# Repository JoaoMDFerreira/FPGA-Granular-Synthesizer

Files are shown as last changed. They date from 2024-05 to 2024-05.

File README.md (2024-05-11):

# FPGA Implementation of a Real-time Synthetic-Based Granular Synthesizer
This repo contains the source code backup of the thesis. The topic of the thesis is "FPGA Implementation of a Real-time Synthetic-Based Granular Synthesizer".
A diagram of the implementation is shown below.
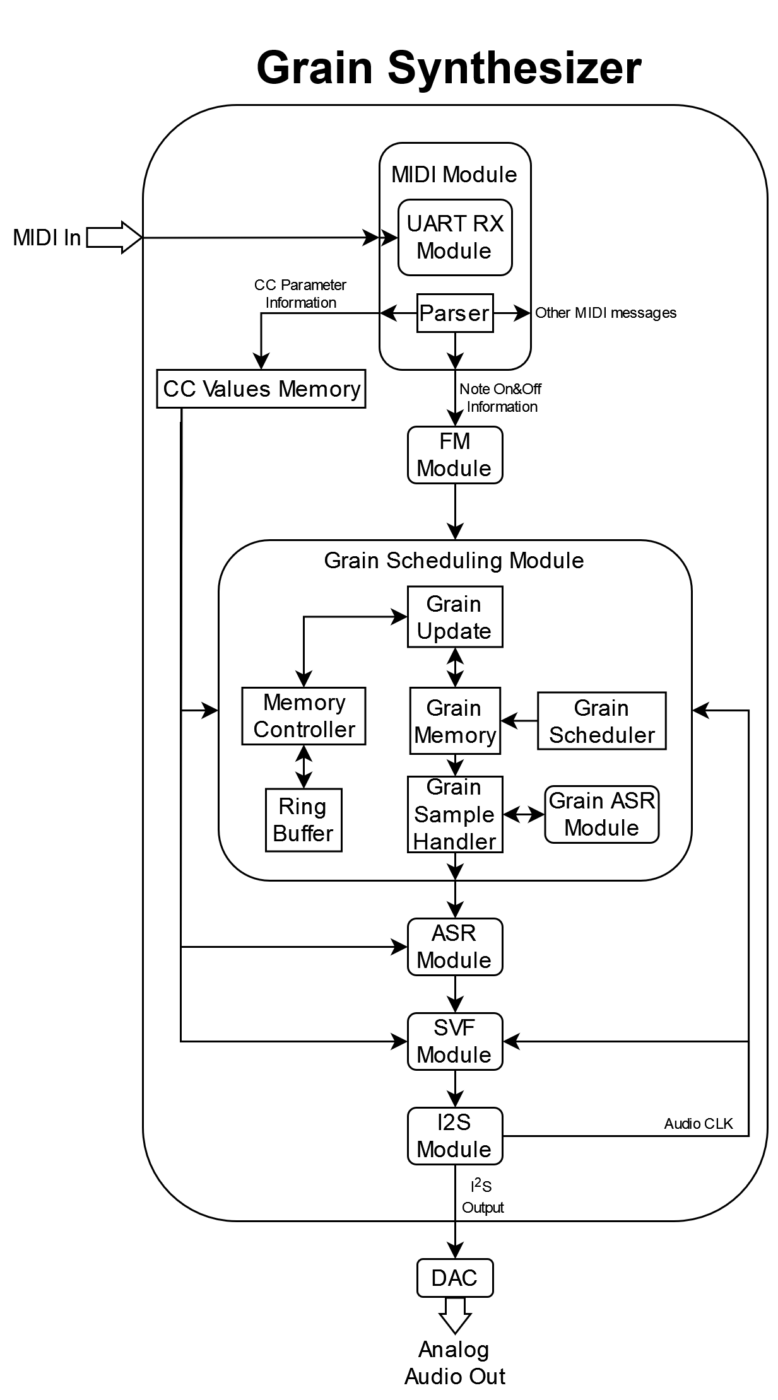
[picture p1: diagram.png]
Implementation Diagram


The final binary is given as BOOT.bin.

## VHDL Source Files
The VHDL project was not backed up, only its source files. These files are available in the vhdl_src folder.

## PCB Files
The KiCad files for a breakout board developed for the Z-turn board V2 are given in the Breakout folder.

## MATLAB Source Files
MATLAB source files are given in the matlab_src.

## Extras
Some extra files are contained in the misc_src folder. Some of these are scripts used to generate plots for the thesis, there are some exploratory scripts towards pitch_shifting that was future work for the thesis and finally there is a C script used to generate code for the MIDI_LUT.

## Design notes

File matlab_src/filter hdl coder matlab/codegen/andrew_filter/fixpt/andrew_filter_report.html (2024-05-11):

### Generated on 2023-07-12 17:33:15

The following table shows fixed point instrumentation results

## Fixed-Point Report andrew_filter

Simulation Coverage | Code
100% | function [y] = andrew_filter(in,MIDI_CC_FREQ,CC_RES,type) persistent low; %https://www.mathworks.com/help/hdlcoder/ug/optimize-feedback-loop-design-and-maintain-high-data-precision-for-hdl-code-generation.html persistent band;
Once | if isempty(low); low = 0; end if isempty(band); band = 0; end
100% | loaded = coder.load('MIDI_CC_to_internal_freq.mat'); filter_internal_freq = loaded.filter_internal_freq; %%check LUT_from_MIDI_Note.m damp_freq = loaded.damp_freq; freq = filter_internal_freq(MIDI_CC_FREQ+1); res = CC_RES/127.0; damp=min(2.0*(1.0 -res*2^-2), damp_freq(MIDI_CC_FREQ+1)); notch = in - damp*band; low = low + freq*band; high = notch - low; band = freq*high + band; switch type
25% | case 1 out = 0.5*high; case 3 out = 0.5*notch; case 2 out = 0.5*band; otherwise out = 0.5*low;
100% | end notch = in - damp*band; low = low + freq*band; high = notch - low; band = freq*high + band; switch type
25% | case 1 y = out + 0.5*high; case 3 y = out + 0.5*notch; case 2 y = out + 0.5*band; otherwise y = out + 0.5*low;
100% | end y = floor(y); end

Variable Name | Type | Sim Min | Sim Max | Static Min | Static Max | Whole Number | ProposedType (Best For WL = 16)
CC_RES | double | 0 | 127 | | | Yes | numerictype(0, 7, 0)
MIDI_CC_FREQ | double | 0 | 127 | | | Yes | numerictype(0, 7, 0)
band | double | -32311.663196332738 | 34925.41665146108 | | | No | numerictype(1, 16, -1)
damp | double | 1.2326752784371549 | 2 | | | No | numerictype(0, 16, 14)
damp_freq | double 1 x 128 | 1.2326752784371549 | 2 | | | No | numerictype(0, 16, 14)
filter_internal_freq | double 1 x 128 | 0.0005351047813369359 | 1.1166838558950394 | | | No | numerictype(0, 16, 15)
freq | double | 0.0005351047813369359 | 1.1166838558950394 | | | No | numerictype(0, 16, 15)
high | double | -60151.40516233119 | 56730.470785388075 | | | No | numerictype(1, 16, -1)
in | double | -32757.127079136506 | 32765.90295982157 | | | No | numerictype(1, 16, 0)
loaded | struct
loaded.damp_freq | double 1 x 128 | 1.2326752784371549 | 2 | | | No | numerictype(0, 16, 14)
loaded.filter_internal_freq | double 1 x 128 | 0.0005351047813369359 | 1.1166838558950394 | | | No | numerictype(0, 16, 15)
low | double | -42841.7216706145 | 49985.56701657598 | | | No | numerictype(1, 16, -1)
notch | double | -55979.872226648375 | 68487.43844321661 | | | No | numerictype(1, 16, -2)
out | double | -27989.936113324187 | 34243.719221608306 | | | No | numerictype(1, 16, -1)
res | double | 0 | 1 | | | No | numerictype(0, 16, 15)
type | double | 0 | 3 | | | Yes | numerictype(0, 2, 0)
y | double | -48295 | 38426.585370044944 | | | No | numerictype(1, 16, -1)

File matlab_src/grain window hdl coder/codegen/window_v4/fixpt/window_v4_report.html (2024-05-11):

### Generated on 2024-03-03 22:46:27

The following table shows fixed point instrumentation results

## Fixed-Point Report window_v4

Simulation Coverage | Code
100% | function out = window_v4(CC_attack, CC_release,current,size,in) persistent interrim_1;
Once | if isempty(interrim_1) interrim_1 = 1; end
100% | persistent interrim_2;
Once | if isempty(interrim_2) interrim_2 = 1; end
100% | attack = floor((CC_attack+1)/255 *size)+1; release = floor((CC_release+1)/255 *size)+1;
24% | if current <= attack interrim_1 = (current-1) *in; out = interrim_1/attack;
52% | elseif current < size - release out = in;
24% | else %out = (size - current) /release *in; interrim_2 = (size-current) *in; out = interrim_2/release; end
100% | end

Variable Name | Type | Sim Min | Sim Max | Static Min | Static Max | Whole Number | ProposedType (Best For WL = 16)
CC_attack | double | 0 | 120 | | | Yes | numerictype(0, 7, 0)
CC_release | double | 0 | 120 | | | Yes | numerictype(0, 7, 0)
attack | double | 1 | 2278 | | | Yes | numerictype(0, 12, 0)
current* | double | 1 | 4800 | | | Yes | numerictype(0, 13, 0)
in | double | -32766.998244725935 | 32766.999999688083 | | | No | numerictype(1, 16, 0)
interrim_1* | double | -74569691.77370726 | 66876492.439555064 | | | No | numerictype(1, 28, 0)
interrim_2* | double | -66876492.43955507 | 74628348.0223639 | | | No | numerictype(1, 28, 0)
out | double | -32766.998244725935 | 32766.998244725935 | | | No | numerictype(1, 16, 0)
release | double | 1 | 2278 | | | Yes | numerictype(0, 12, 0)
size* | double | 1 | 4800 | | | Yes | numerictype(0, 13, 0)

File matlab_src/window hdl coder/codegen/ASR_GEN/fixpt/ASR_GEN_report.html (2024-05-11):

### Generated on 2024-02-12 22:14:36

The following table shows fixed point instrumentation results

## Fixed-Point Report ASR_GEN

Simulation Coverage | Code
100% | function ASR_OUT = ASR_GEN(ATTACK_CC, RELEASE_CC,MAX_ATTACK_MS,MAX_RELEASE_MS,CLK_FREQ,NOTE_ON,ASR_IN) % 0 => Idle; 1 => Attack; 2 => Sustain; 3 => Release persistent state;
Once | if isempty(state) state = 0; end
100% | persistent attack_ptr;
Once | if isempty(attack_ptr) attack_ptr = 0; end
100% | persistent release_ptr;
Once | if isempty(release_ptr) release_ptr = 0; end
100% | attack_clks = floor(CLK_FREQ*MAX_ATTACK_MS/1000 *ATTACK_CC/128); release_clks = floor(CLK_FREQ*MAX_RELEASE_MS/1000 *RELEASE_CC/128); switch state
32% | case 0 %Idle state ASR_OUT = 0;

100%

if NOTE_ON == 1
attack_ptr = 0;
state = 1;
end

case 1 %Attack state
if NOTE_ON == 1
if attack_ptr >= attack_clks
state = 2;
end
else
state = 3;
release_ptr = attack_ptr;
end
if attack_clks == 0
ASR_OUT = 0;
else
ASR_OUT = floor(attack_ptr/attack_clks *ASR_IN);
end
attack_ptr = attack_ptr + 1;

case 2 %Sustain state
ASR_OUT = ASR_IN;
if NOTE_ON == 0
state = 3;
release_ptr = release_clks;
end

case 3 %Release state
if NOTE_ON == 1 || release_ptr == 0
state = 0;
else
release_ptr = release_ptr - 1;
end
if release_clks == 0
ASR_OUT = 0;
else
ASR_OUT = floor(release_ptr/release_clks *ASR_IN);
end

otherwise
ASR_OUT = 0;
state = 0;
end
end

Variable Name | Type | Sim Min | Sim Max | Static Min | Static Max | Whole Number | ProposedType (Best For WL = 16)
ASR_IN | double | -32766.999561272904 | 32766.99956127291 | | | No | numerictype(1, 16, 0)
ASR_OUT | double | -32766.999561272904 | 32766.989031823246 | | | No | numerictype(1, 16, 0)
ATTACK_CC | double | 0 | 120 | | | Yes | numerictype(0, 7, 0)
CLK_FREQ* | double | 48000 | 48000 | | | Yes | numerictype(0, 27, 0)
MAX_ATTACK_MS* | double | 100 | 100 | | | Yes | numerictype(0, 10, 0)
MAX_RELEASE_MS* | double | 100 | 100 | | | Yes | numerictype(0, 10, 0)
NOTE_ON | double | 0 | 1 | | | Yes | numerictype(0, 1, 0)
RELEASE_CC | double | 0 | 120 | | | Yes | numerictype(0, 7, 0)
attack_clks* | double | 0 | 4500 | | | Yes | numerictype(0, 27, 0)
attack_ptr* | double | 0 | 4319 | | | Yes | numerictype(0, 27, 0)
release_clks* | double | 0 | 4500 | | | Yes | numerictype(0, 27, 0)
release_ptr* | double | 0 | 4318 | | | Yes | numerictype(0, 27, 0)
state | double | 0 | 3 | | | Yes | numerictype(0, 2, 0)

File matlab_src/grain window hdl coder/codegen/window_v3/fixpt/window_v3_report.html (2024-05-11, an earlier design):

### Generated on 2024-02-04 21:20:42

The following table shows fixed point instrumentation results

## Fixed-Point Report window_v3

Simulation Coverage | Code
100% | function out = window_v3(CC_attack, CC_release,current,size,in) attack = floor((CC_attack+1)/255 *size)+1; release = floor((CC_release+1)/255 *size)+1; sustain = size - attack - release;
24% | if current <= attack out = (current-1)/attack *in;
52% | elseif current < attack + sustain out = in;
24% | else out = (1 - (current - attack - sustain)/release) *in; end
100% | end

Variable Name | Type | Sim Min | Sim Max | Static Min | Static Max | Whole Number | ProposedType (Best For WL = 16)
CC_attack | double | 0 | 120 | | | Yes | numerictype(0, 7, 0)
CC_release | double | 0 | 120 | | | Yes | numerictype(0, 7, 0)
attack | double | 1 | 22303 | | | Yes | numerictype(0, 15, 0)
current | double | 1 | 47001 | | | Yes | numerictype(0, 16, 0)
in | double | -32766.999999998614 | 32766.999999998156 | | | No | numerictype(1, 16, 0)
out | double | -32766.999952809816 | 32766.999955083706 | | | No | numerictype(1, 16, 0)
release | double | 1 | 22303 | | | Yes | numerictype(0, 15, 0)
size | double | 1 | 47001 | | | Yes | numerictype(0, 16, 0)
sustain | double | -1 | 46631 | | | Yes | numerictype(1, 17, 0)

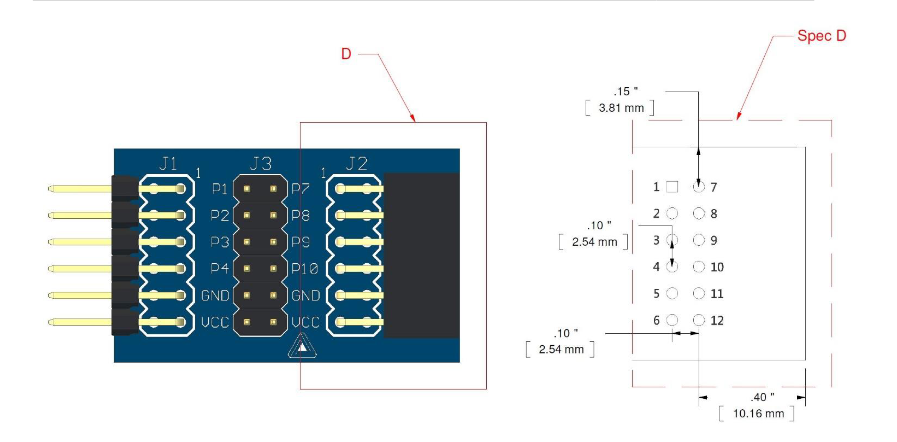
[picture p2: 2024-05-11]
Breakout/Breakout/PMOD.png

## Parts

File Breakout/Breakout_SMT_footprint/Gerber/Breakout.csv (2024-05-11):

Comment | Designator | Footprint | LCSC Part Number
1N4148 | D1 | Device:D | C402212
3mm LED | D2, D3, D4, D5, D6, D7, D8, D9 | Device:LED | C7433021
2x06 Right Angle Pin Header 2.54mm | J1, J3 | Z_Turn_Board_Lib:PMOD_Conn | C5383091
DIN-5_180Degree_Female | J2 | Connector:DIN-5_180degree | C2939346
1x06 Right Angle Pin Header 2.54mm | J4 | Connector:Conn_01x06_Pin | C19190480
1x32 Straight Pin Header 2.54mm | J5 | Connector:Conn_01x31_Pin | C7430388
1x04 Right Angle Pin Header 2.54mm | J6 | Connector:Conn_01x04_Pin | C2935929
02x40 Straight Pin Header 1.27mm | J7, J8 | Connector_Generic:Conn_02x40_Odd_Even | C545212
220R | R1 | Device:R_Small | C1367947
510R | R2 | Device:R_Small | C1396546
H11L1 | U1 | Isolator:H11L1 | C78588

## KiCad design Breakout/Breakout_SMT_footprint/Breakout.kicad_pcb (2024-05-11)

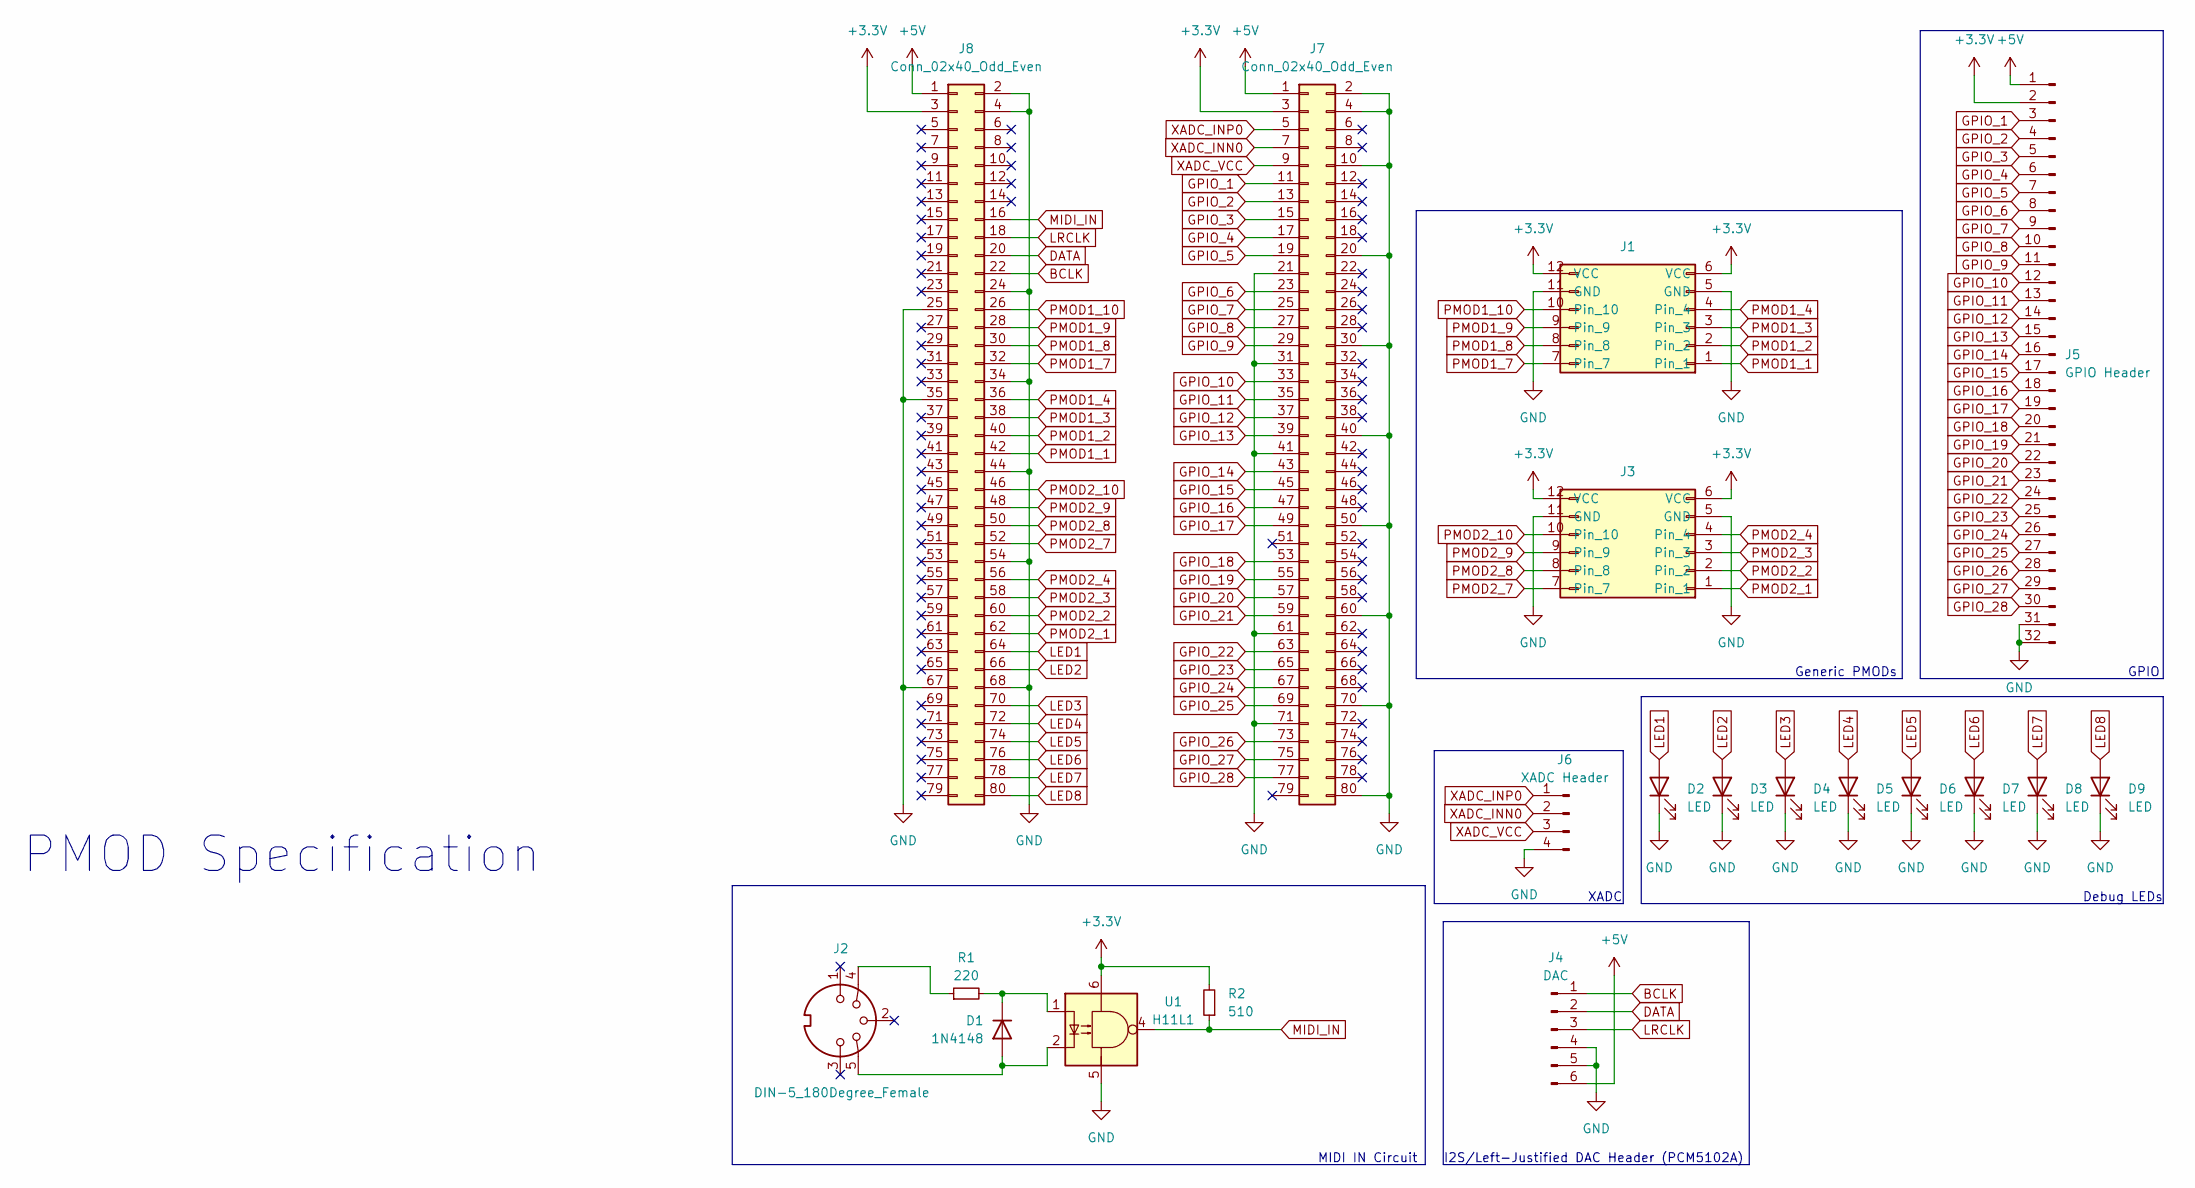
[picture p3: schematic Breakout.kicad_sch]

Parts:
D1: 1N4148; D_DO-35_SOD27_P7.62mm_Horizontal; LCSC C402212
D2, D3, D4, D5, D6, D7, D8, D9: LED; LED_D3.0mm; LCSC C7433021
J1, J3: PMOD; LCSC C5383091
J2: DIN-5_180Degree_Female; MIDI_DIN5; LCSC C2939346
J4: DAC; PinHeader_1x06_P2.54mm_Horizontal; LCSC C19190480
J5: GPIO Header; PinHeader_1x32_P2.54mm_Vertical; LCSC C7430388
J6: XADC Header; PinSocket_1x04_P2.54mm_Vertical; LCSC C2935929
J7, J8: Conn_02x40_Odd_Even; 2x40 Inverted; LCSC C545212
R1: 220; R_Axial_DIN0204_L3.6mm_D1.6mm_P5.08mm_Horizontal; LCSC C1367947
R2: 510; R_Axial_DIN0204_L3.6mm_D1.6mm_P5.08mm_Horizontal; LCSC C1396546
U1: H11L1; DIP-6_W7.62mm_Socket_LongPads; LCSC C78588

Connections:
+3.3V: J1.6 (VCC), J1.12 (VCC), J3.6 (VCC), J3.12 (VCC), J5.2, J7.3, J8.3, R2.2, U1.6
+5V: J4.6, J5.1, J7.1, J8.1
BCLK: J4.1, J8.22
DATA: J4.2, J8.20
GND: D2.1 (K), D3.1 (K), D4.1 (K), D5.1 (K), D6.1 (K), D7.1 (K), D8.1 (K), D9.1 (K), J1.5 (GND), J1.11 (GND), J3.5 (GND), J3.11 (GND), J4.4, J4.5, J5.31, J5.32, J6.4, J7.2, J7.4, J7.10, J7.20, J7.21, J7.30, J7.31, J7.40, J7.41, J7.50, J7.60, J7.61, J7.70, J7.71, J7.80, J8.2, J8.4, J8.24, J8.25, J8.34, J8.35, J8.44, J8.54, J8.67, J8.68, U1.5
GPIO_1: J5.3, J7.11
GPIO_2: J5.4, J7.13
GPIO_3: J5.5, J7.15
GPIO_4: J5.6, J7.17
GPIO_5: J5.7, J7.19
GPIO_6: J5.8, J7.23
GPIO_7: J5.9, J7.25
GPIO_8: J5.10, J7.27
GPIO_9: J5.11, J7.29
GPIO_10: J5.12, J7.33
GPIO_11: J5.13, J7.35
GPIO_12: J5.14, J7.37
GPIO_13: J5.15, J7.39
GPIO_14: J5.16, J7.43
GPIO_15: J5.17, J7.45
GPIO_16: J5.18, J7.47
GPIO_17: J5.19, J7.49
GPIO_18: J5.20, J7.53
GPIO_19: J5.21, J7.55
GPIO_20: J5.22, J7.57
GPIO_21: J5.23, J7.59
GPIO_22: J5.24, J7.63
GPIO_23: J5.25, J7.65
GPIO_24: J5.26, J7.67
GPIO_25: J5.27, J7.69
GPIO_26: J5.28, J7.73
GPIO_27: J5.29, J7.75
GPIO_28: J5.30, J7.77
LED1: D2.2 (A), J8.64
LED2: D3.2 (A), J8.66
LED3: D4.2 (A), J8.70
LED4: D5.2 (A), J8.72
LED5: D6.2 (A), J8.74
LED6: D7.2 (A), J8.76
LED7: D8.2 (A), J8.78
LED8: D9.2 (A), J8.80
LRCLK: J4.3, J8.18
MIDI_IN: J8.16, R2.1, U1.4
unnamed: D1.2 (A), J2.5, U1.2
unnamed: D1.1 (K), R1.2, U1.1
unnamed: J2.4, R1.1
PMOD1_1: J1.1, J8.42
PMOD1_2: J1.2, J8.40
PMOD1_3: J1.3, J8.38
PMOD1_4: J1.4, J8.36
PMOD1_7: J1.7, J8.32
PMOD1_8: J1.8, J8.30
PMOD1_9: J1.9, J8.28
PMOD1_10: J1.10, J8.26
PMOD2_1: J3.1, J8.62
PMOD2_2: J3.2, J8.60
PMOD2_3: J3.3, J8.58
PMOD2_4: J3.4, J8.56
PMOD2_7: J3.7, J8.52
PMOD2_8: J3.8, J8.50
PMOD2_9: J3.9, J8.48
PMOD2_10: J3.10, J8.46
XADC_INN0: J6.2, J7.7
XADC_INP0: J6.1, J7.5
XADC_VCC: J6.3, J7.9

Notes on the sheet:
PMOD Specification
I2S/Left-Justified DAC Header (PCM5102A)
GPIO
Generic PMODs
Debug LEDs
MIDI IN Circuit
XADC

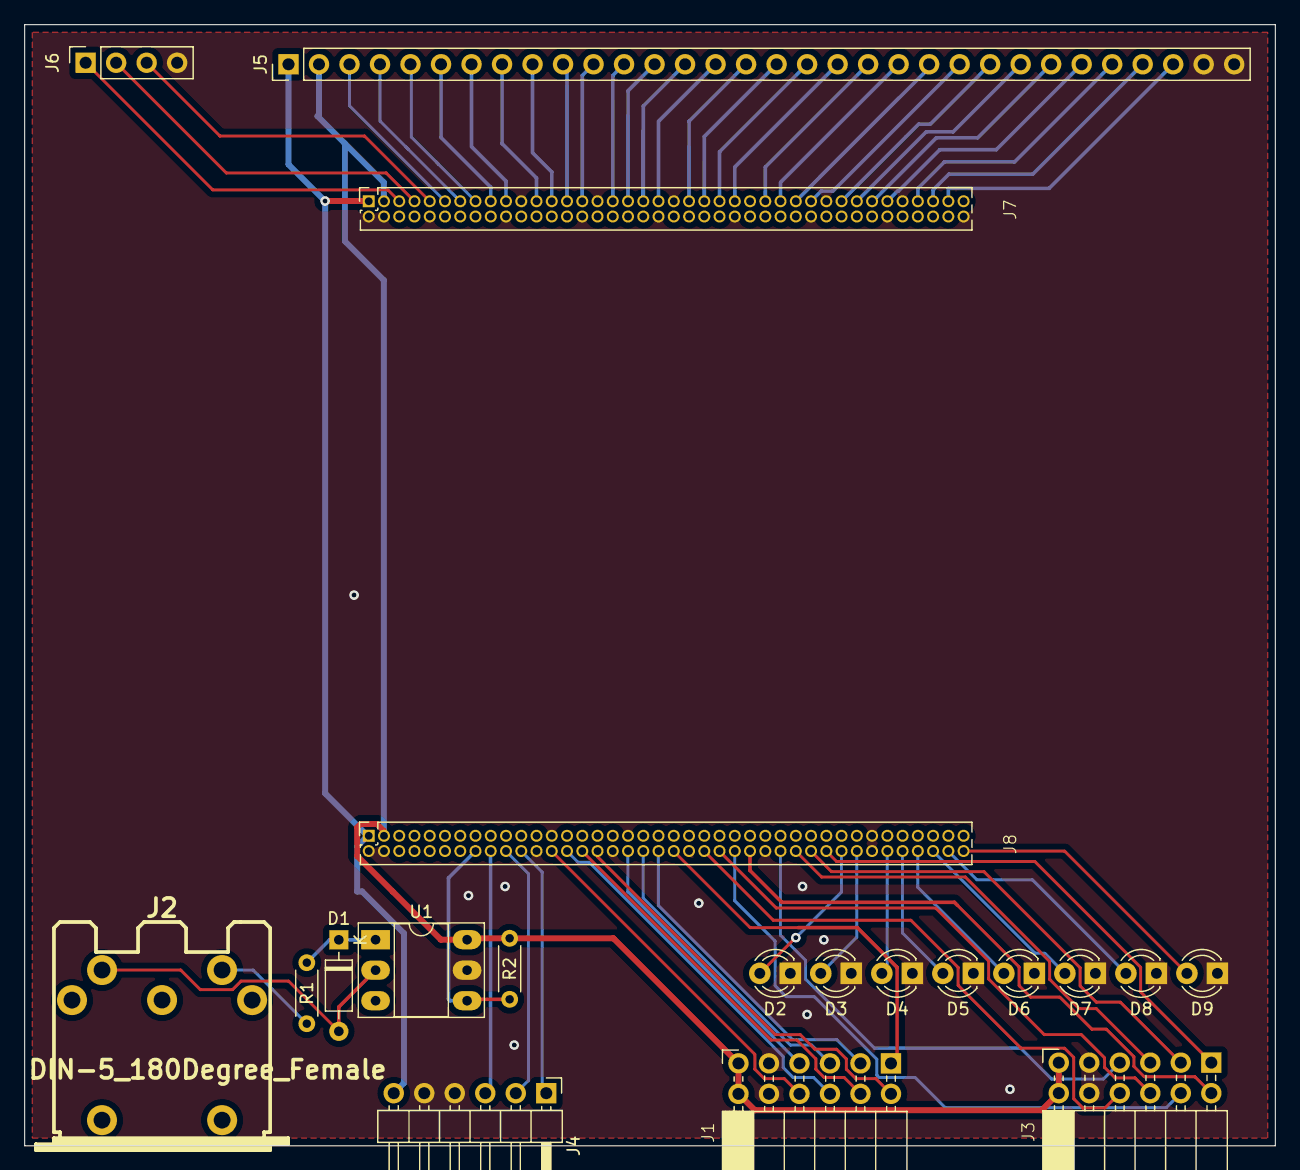
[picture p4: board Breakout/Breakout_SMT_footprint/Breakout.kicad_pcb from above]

Board: 2 copper layers, 104.1 x 93.3 mm, 20 parts (0 on the bottom side), 65 nets.

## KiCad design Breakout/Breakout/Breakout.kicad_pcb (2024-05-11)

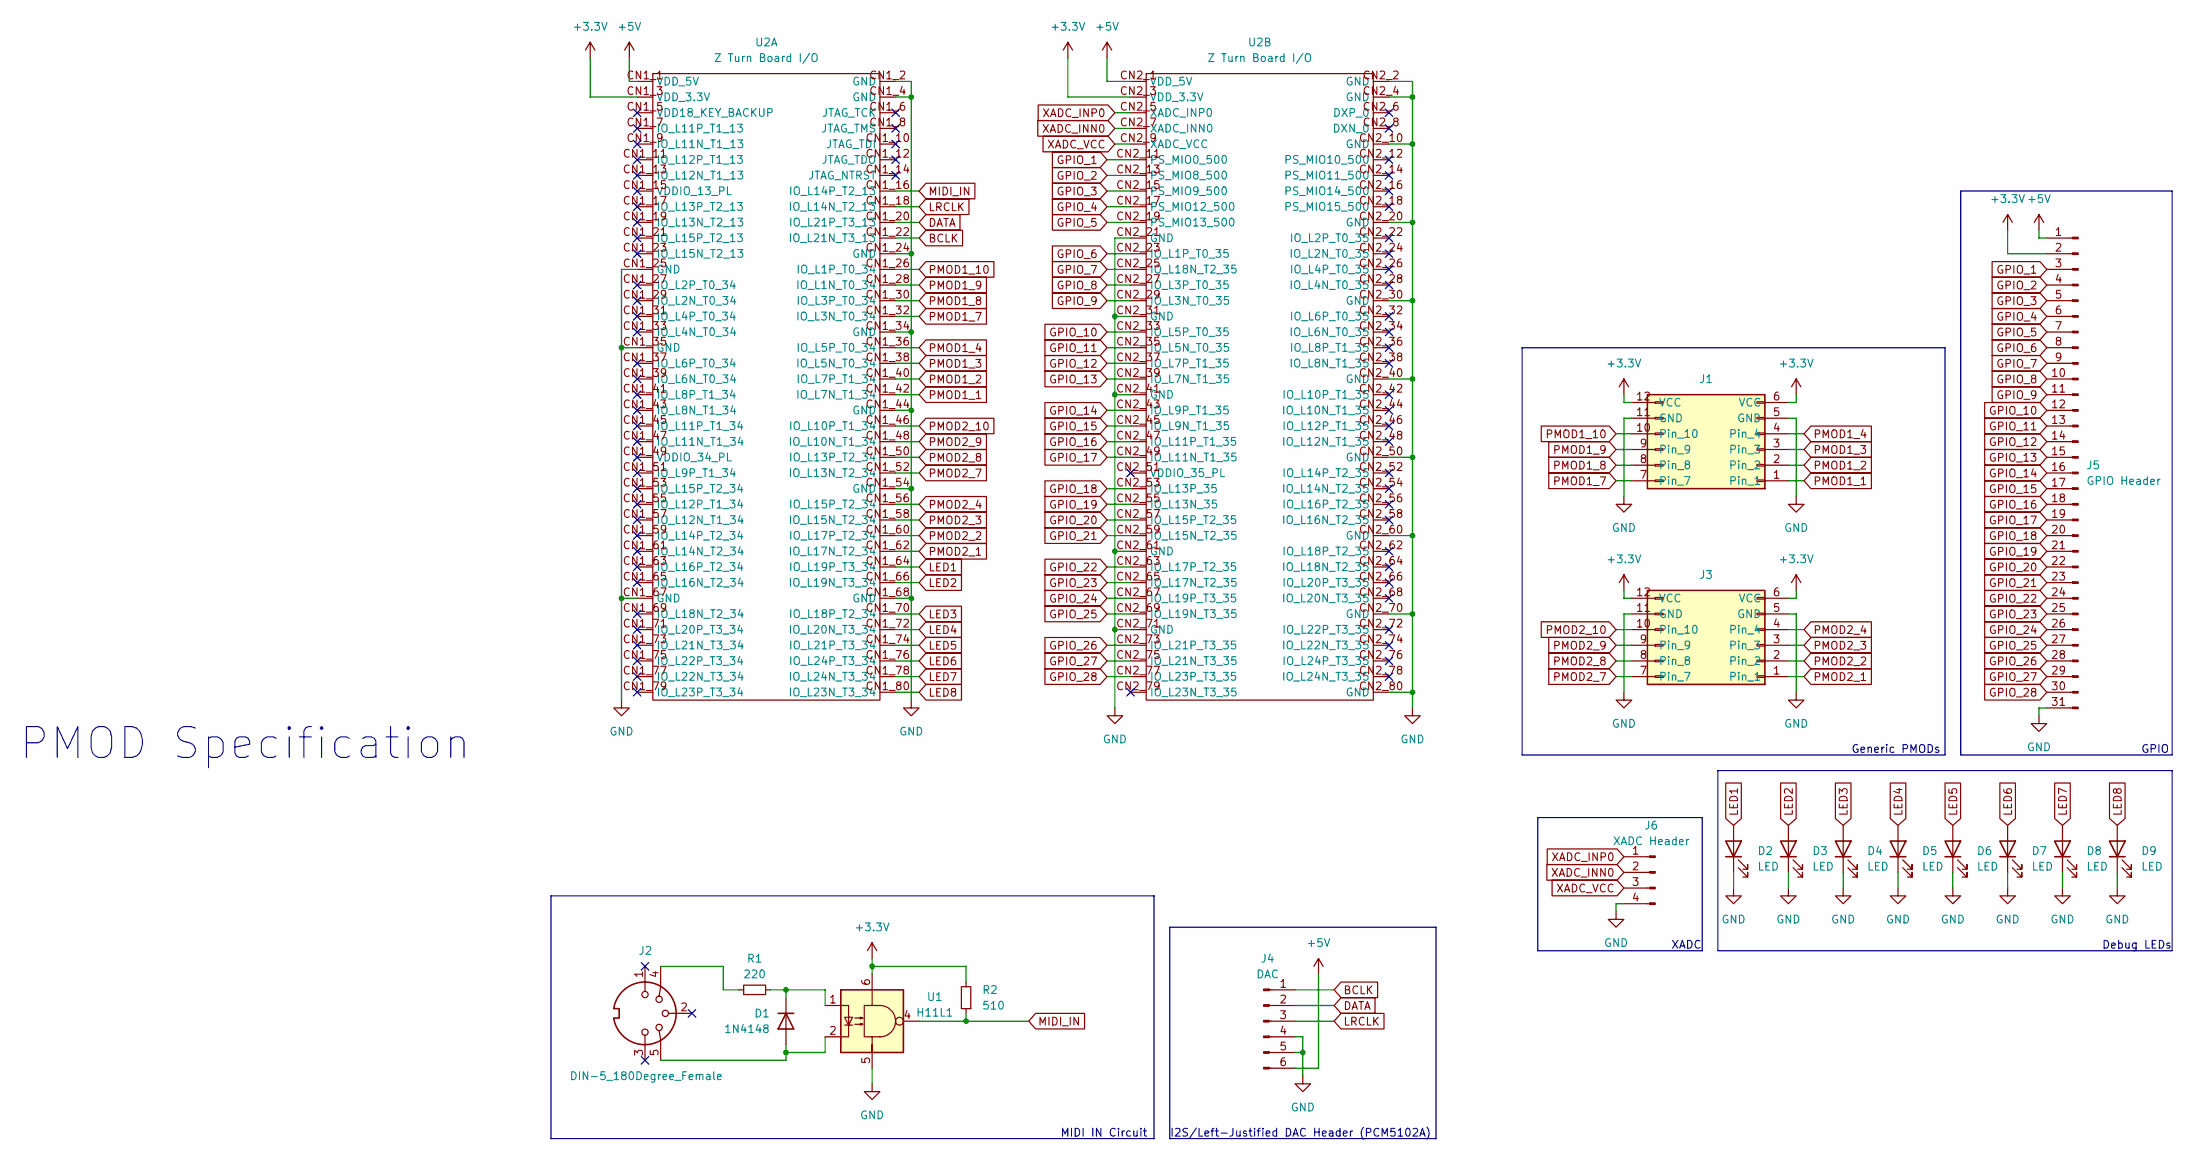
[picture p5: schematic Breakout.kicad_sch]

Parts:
D1: 1N4148; D_DO-35_SOD27_P7.62mm_Horizontal; LCSC C402212
D2, D3, D4, D5, D6, D7, D8, D9: LED; LED_D3.0mm; LCSC C7433021
J1, J3: PMOD; LCSC C5383091
J2: DIN-5_180Degree_Female; MIDI_DIN5; LCSC C2939346
J4: DAC; PinHeader_1x06_P2.54mm_Horizontal; LCSC C19190480
J5: GPIO Header; PinSocket_1x31_P2.54mm_Vertical; LCSC C2883719
J6: XADC Header; PinSocket_1x04_P2.54mm_Vertical; LCSC C18164982
R1: 220; R_Axial_DIN0204_L3.6mm_D1.6mm_P5.08mm_Horizontal; LCSC C1367947
R2: 510; R_Axial_DIN0204_L3.6mm_D1.6mm_P5.08mm_Horizontal; LCSC C1396546
U1: H11L1; DIP-6_W7.62mm_Socket_LongPads; LCSC C78588
U2: Z Turn Board I/O; Z Turn Board IO; LCSC C545212

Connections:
+3.3V: J1.6 (VCC), J1.12 (VCC), J3.6 (VCC), J3.12 (VCC), J5.2, R2.2, U1.6, U2.CN1_3 (VDD_3.3V), U2.CN2_3 (VDD_3.3V)
+5V: J4.6, J5.1, U2.CN1_1 (VDD_5V), U2.CN2_1 (VDD_5V)
BCLK: J4.1, U2.CN1_22 (IO_L21N_T3_13)
DATA: J4.2, U2.CN1_20 (IO_L21P_T3_13)
GND: D2.1 (K), D3.1 (K), D4.1 (K), D5.1 (K), D6.1 (K), D7.1 (K), D8.1 (K), D9.1 (K), J1.5 (GND), J1.11 (GND), J3.5 (GND), J3.11 (GND), J4.4, J4.5, J5.31, J6.4, U1.5, U2.CN1_2 (GND), U2.CN1_4 (GND), U2.CN1_24 (GND), U2.CN1_25 (GND), U2.CN1_34 (GND), U2.CN1_35 (GND), U2.CN1_44 (GND), U2.CN1_54 (GND), U2.CN1_67 (GND), U2.CN1_68 (GND), U2.CN2_2 (GND), U2.CN2_4 (GND), U2.CN2_10 (GND), U2.CN2_20 (GND), U2.CN2_21 (GND), U2.CN2_30 (GND), U2.CN2_31 (GND), U2.CN2_40 (GND), U2.CN2_41 (GND), U2.CN2_50 (GND), U2.CN2_60 (GND), U2.CN2_61 (GND), U2.CN2_70 (GND), U2.CN2_71 (GND), U2.CN2_80 (GND)
GPIO_1: J5.3, U2.CN2_11 (PS_MIO0_500)
GPIO_2: J5.4, U2.CN2_13 (PS_MIO8_500)
GPIO_3: J5.5, U2.CN2_15 (PS_MIO9_500)
GPIO_4: J5.6, U2.CN2_17 (PS_MIO12_500)
GPIO_5: J5.7, U2.CN2_19 (PS_MIO13_500)
GPIO_6: J5.8, U2.CN2_23 (IO_L1P_T0_35)
GPIO_7: J5.9, U2.CN2_25 (IO_L18N_T2_35)
GPIO_8: J5.10, U2.CN2_27 (IO_L3P_T0_35)
GPIO_9: J5.11, U2.CN2_29 (IO_L3N_T0_35)
GPIO_10: J5.12, U2.CN2_33 (IO_L5P_T0_35)
GPIO_11: J5.13, U2.CN2_35 (IO_L5N_T0_35)
GPIO_12: J5.14, U2.CN2_37 (IO_L7P_T1_35)
GPIO_13: J5.15, U2.CN2_39 (IO_L7N_T1_35)
GPIO_14: J5.16, U2.CN2_43 (IO_L9P_T1_35)
GPIO_15: J5.17, U2.CN2_45 (IO_L9N_T1_35)
GPIO_16: J5.18, U2.CN2_47 (IO_L11P_T1_35)
GPIO_17: J5.19, U2.CN2_49 (IO_L11N_T1_35)
GPIO_18: J5.20, U2.CN2_53 (IO_L13P_35)
GPIO_19: J5.21, U2.CN2_55 (IO_L13N_35)
GPIO_20: J5.22, U2.CN2_57 (IO_L15P_T2_35)
GPIO_21: J5.23, U2.CN2_59 (IO_L15N_T2_35)
GPIO_22: J5.24, U2.CN2_63 (IO_L17P_T2_35)
GPIO_23: J5.25, U2.CN2_65 (IO_L17N_T2_35)
GPIO_24: J5.26, U2.CN2_67 (IO_L19P_T3_35)
GPIO_25: J5.27, U2.CN2_69 (IO_L19N_T3_35)
GPIO_26: J5.28, U2.CN2_73 (IO_L21P_T3_35)
GPIO_27: J5.29, U2.CN2_75 (IO_L21N_T3_35)
GPIO_28: J5.30, U2.CN2_77 (IO_L23P_T3_35)
LED1: D2.2 (A), U2.CN1_64 (IO_L19P_T3_34)
LED2: D3.2 (A), U2.CN1_66 (IO_L19N_T3_34)
LED3: D4.2 (A), U2.CN1_70 (IO_L18P_T2_34)
LED4: D5.2 (A), U2.CN1_72 (IO_L20N_T3_34)
LED5: D6.2 (A), U2.CN1_74 (IO_L21P_T3_34)
LED6: D7.2 (A), U2.CN1_76 (IO_L24P_T3_34)
LED7: D8.2 (A), U2.CN1_78 (IO_L24N_T3_34)
LED8: D9.2 (A), U2.CN1_80 (IO_L23N_T3_34)
LRCLK: J4.3, U2.CN1_18 (IO_L14N_T2_13)
MIDI_IN: R2.1, U1.4, U2.CN1_16 (IO_L14P_T2_13)
unnamed: D1.2 (A), J2.5, U1.2
unnamed: D1.1 (K), R1.2, U1.1
unnamed: J2.4, R1.1
PMOD1_1: J1.1, U2.CN1_42 (IO_L7N_T1_34)
PMOD1_2: J1.2, U2.CN1_40 (IO_L7P_T1_34)
PMOD1_3: J1.3, U2.CN1_38 (IO_L5N_T0_34)
PMOD1_4: J1.4, U2.CN1_36 (IO_L5P_T0_34)
PMOD1_7: J1.7, U2.CN1_32 (IO_L3N_T0_34)
PMOD1_8: J1.8, U2.CN1_30 (IO_L3P_T0_34)
PMOD1_9: J1.9, U2.CN1_28 (IO_L1N_T0_34)
PMOD1_10: J1.10, U2.CN1_26 (IO_L1P_T0_34)
PMOD2_1: J3.1, U2.CN1_62 (IO_L17N_T2_34)
PMOD2_2: J3.2, U2.CN1_60 (IO_L17P_T2_34)
PMOD2_3: J3.3, U2.CN1_58 (IO_L15N_T2_34)
PMOD2_4: J3.4, U2.CN1_56 (IO_L15P_T2_34)
PMOD2_7: J3.7, U2.CN1_52 (IO_L13N_T2_34)
PMOD2_8: J3.8, U2.CN1_50 (IO_L13P_T2_34)
PMOD2_9: J3.9, U2.CN1_48 (IO_L10N_T1_34)
PMOD2_10: J3.10, U2.CN1_46 (IO_L10P_T1_34)
XADC_INN0: J6.2, U2.CN2_7 (XADC_INN0)
XADC_INP0: J6.1, U2.CN2_5 (XADC_INP0)
XADC_VCC: J6.3, U2.CN2_9 (XADC_VCC)

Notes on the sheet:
PMOD Specification
I2S/Left-Justified DAC Header (PCM5102A)
GPIO
Generic PMODs
Debug LEDs
MIDI IN Circuit
XADC

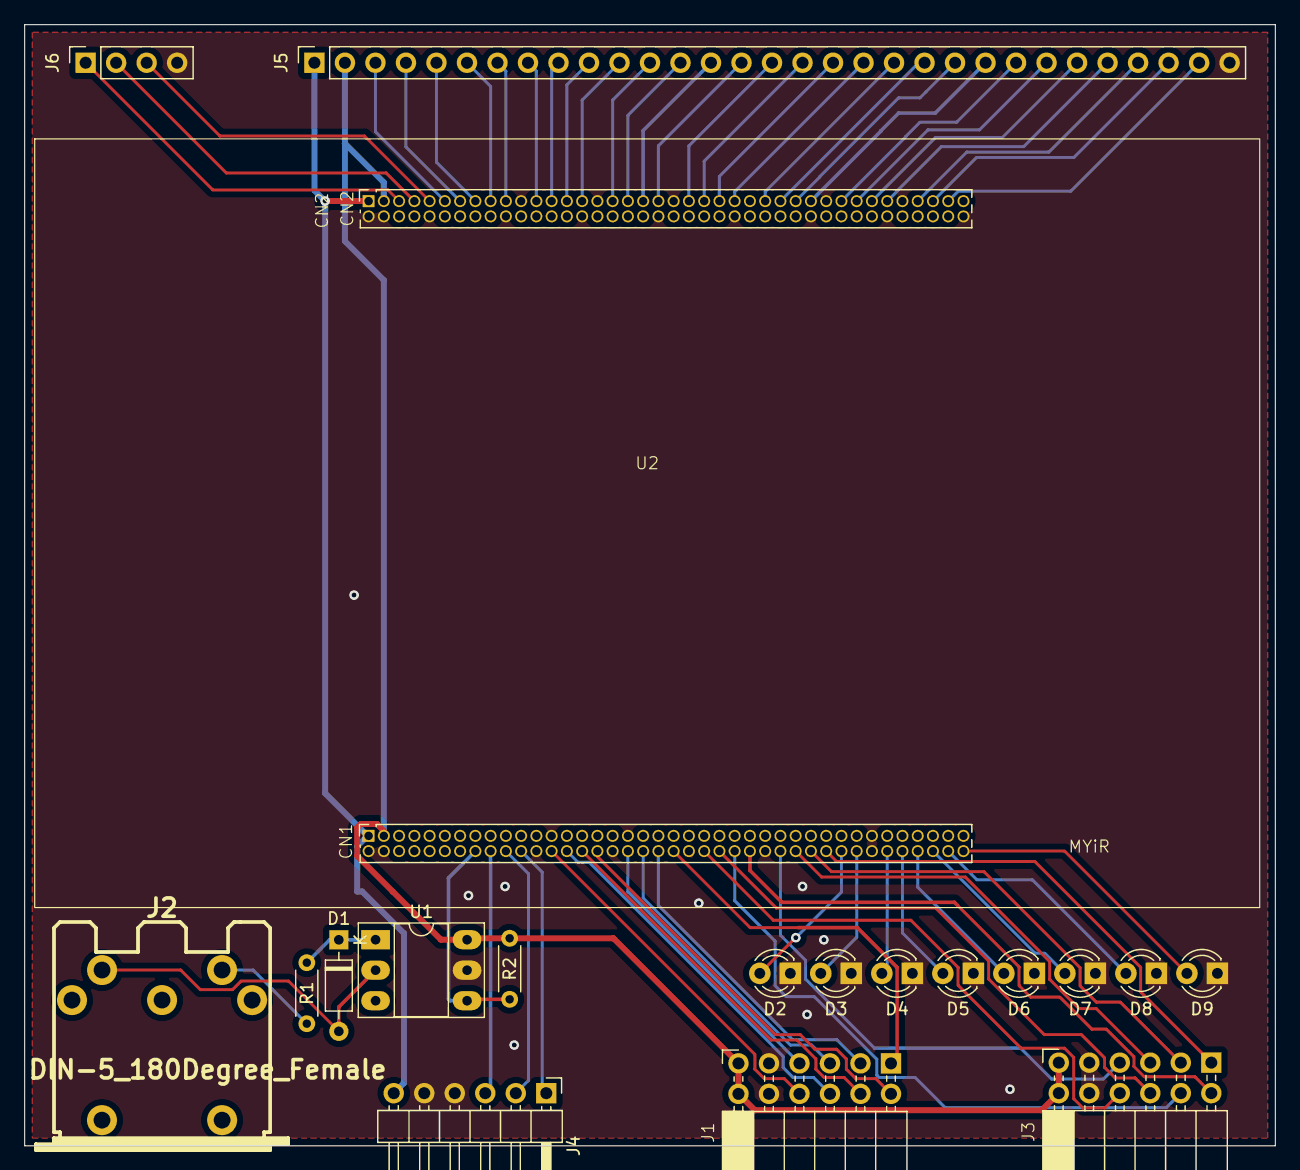
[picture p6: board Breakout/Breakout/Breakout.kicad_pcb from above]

Board: 2 copper layers, 104.1 x 93.3 mm, 19 parts (0 on the bottom side), 65 nets.
